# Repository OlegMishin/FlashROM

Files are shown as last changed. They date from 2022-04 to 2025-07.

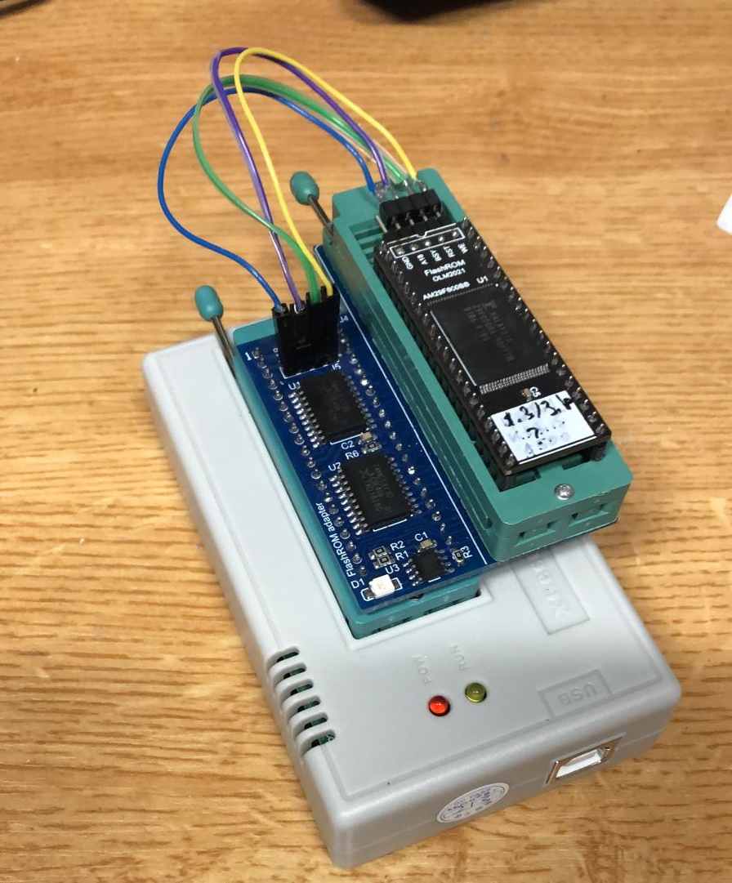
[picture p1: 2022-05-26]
Doc/TL866_flash_writing.jpg

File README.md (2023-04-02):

# FlashROM
Different Flash memory adapters for Commodore/Amiga or other classic computers/devices.

For now there are following types of the FlashROM: 
1. 40pin to be used in Amiga 500.
2. 42 pin designed for my Amiga 1200 but also can be used in A500 rev 8 mainboard.
3. 24 pin for Commodore 64 computers. Replacement for 2316/2332/2364 ROM chips.
4. 28 pin for other devices. Replaces 2764..27512. Supports long and short Flash memory package.

Schematics/BOM and Gerbers located in each ones folder.

# 3D render



# Actual photos

40 pin in A500



42 pin x2 in A1200



24 pin, KERNAL, CHAR, BASIC ROMs replacement in Commodore C64



28 pin



To flash 28 pin FlashROM a simple adapter is needed as the pcb has four test points for flash WE# and extra address lines.
I used a pcb with 32 pin socket and spring needle pins to reach the test points on bottom layer of the pcb.



# FlashAdapter
An adapter for TL866 to program the 16 bit flash memory(40, 42 pin). It based on the circuit:
https://proghq.org/wiki/index.php/TL866_TSOP48_adapter
Circuit diagram, gerbers and ATtiny firmware are in "FlashAdapter" folder.

Four wires required to be connected between the adapter and 40pin FlashROM(as shown below):
A18, #BSY, #RST and #WE. 
For 42pin FlashROM, only needed #BSY, #RST and #WE as A18 and A19 already connected via socket's pins 1 and 2.



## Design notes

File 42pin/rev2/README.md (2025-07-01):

# Using the adapter in different Amiga boards

1. The 42 pin adapter designed mostly for A1200 boards but it can be used in A500 boards as well.
2. Take care about A18 and A19 address inputs of the adapter. In case of 1MiB Flash ROM typically Kickstart ROM can be programmed to two locations: 0x00000 and 0x80000 to let KS start regardless of A18 state.

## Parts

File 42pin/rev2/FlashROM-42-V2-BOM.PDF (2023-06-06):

Bill of Materials | | FlashROM adapter

## (42 pin)

Revision | 2.0
Created by | OLM
Creation date | 06.06.2023 | 21:20:03
Print date | 06.06.2023 | 21:20:09
No. | QuantityDesignator | | Comment | Value | Part | Manufacturer | Description
0 | 1 | C5 | Capacitor | 100nF | 100nF 50VX7R 0603 | | Ceramic capacitor
1 | 1 | J1 | Round pins | 42 pins or x2 single row round male pins | 9081-0-00-15-00-00-08-0‎ | Mill MAx | Round pins
2 | 1 | J2 | Header 6 (2mm) Right angle | PR20C06HBNN | PR20C06HBNN | METZ CONNECT USA Inc. | Header 6 (2mm) Right angle
3 | 4 | R1, R2, R3, R4 | Resistor | 10k | 10k 5% 0603 | | Resistor
4 | 5 | RP2, RP3, RP4, RP5, RP6 | Res. array | 4х10 kOhm | CAT16-103J4 | Bourns | Resistor pack
5 | 1 | U1 | IC | MX29F800CB, 29F800BA | AM29F800BB-70EC | AMD | 8Mb 515K*16 FLASH MEMORY

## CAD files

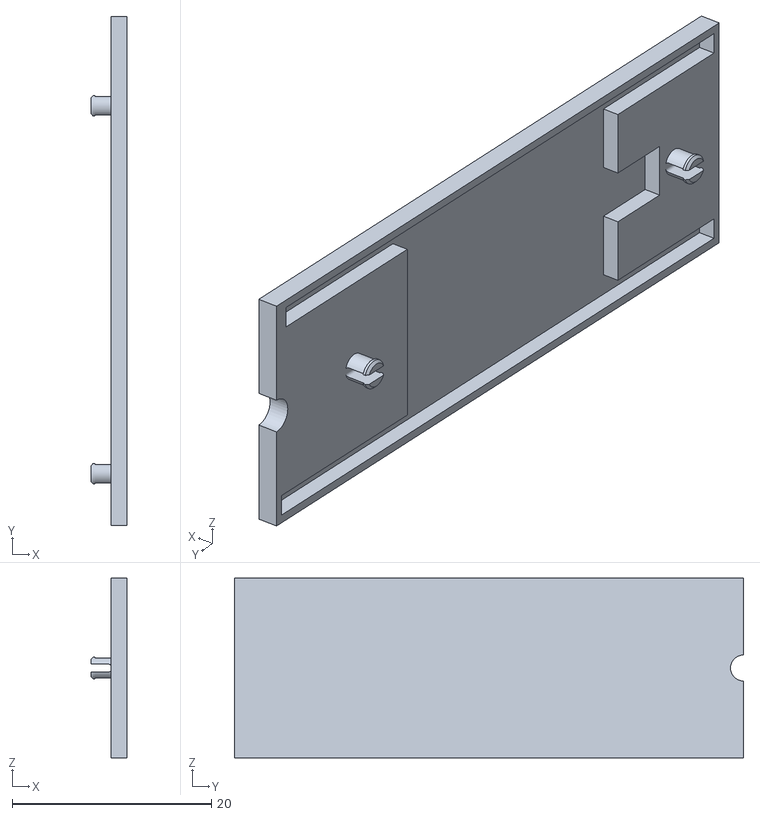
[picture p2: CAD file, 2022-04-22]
40pin/CAD/F40-1-Cover1.STL
3.60 x 51.1 x 18.0

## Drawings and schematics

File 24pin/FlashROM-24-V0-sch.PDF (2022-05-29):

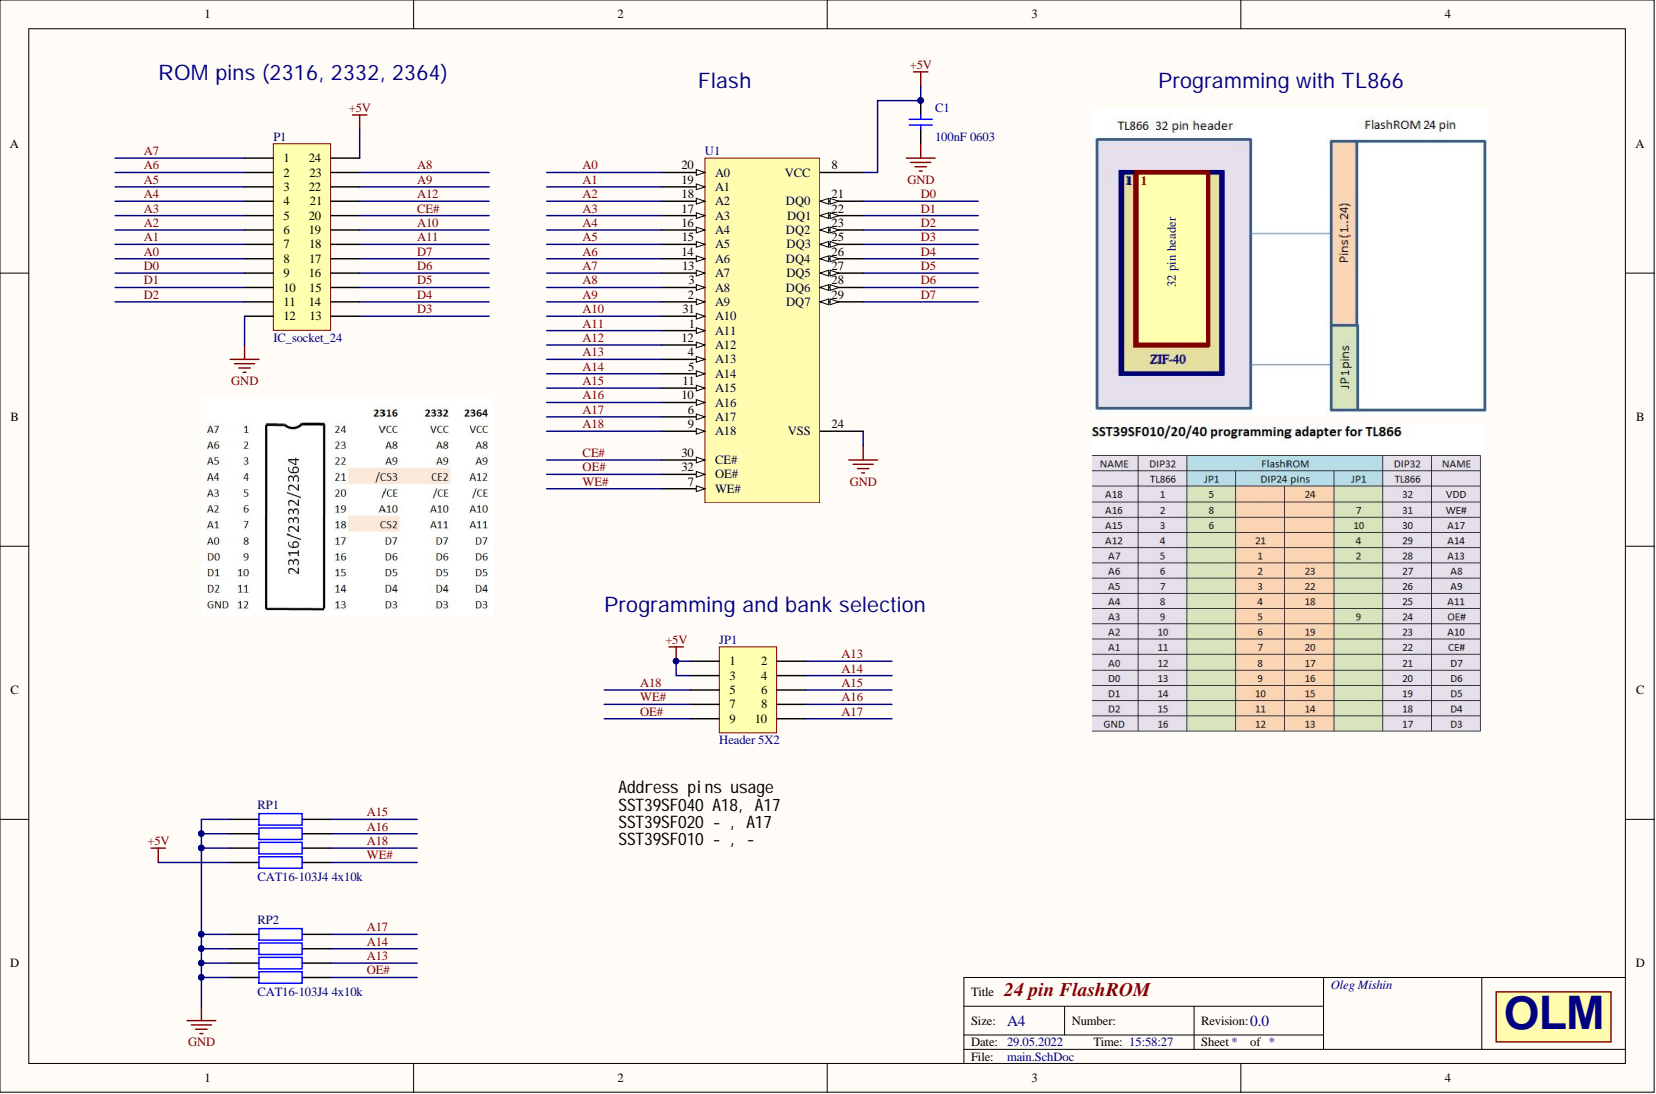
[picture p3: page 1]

Programming and bank selection

24 pin FlashROM Title | Oleg Mishin

Size: | Number: | Revision: 0.0

Date: 29.05.2022 Time: 15:58:27 | | Sheet * of *

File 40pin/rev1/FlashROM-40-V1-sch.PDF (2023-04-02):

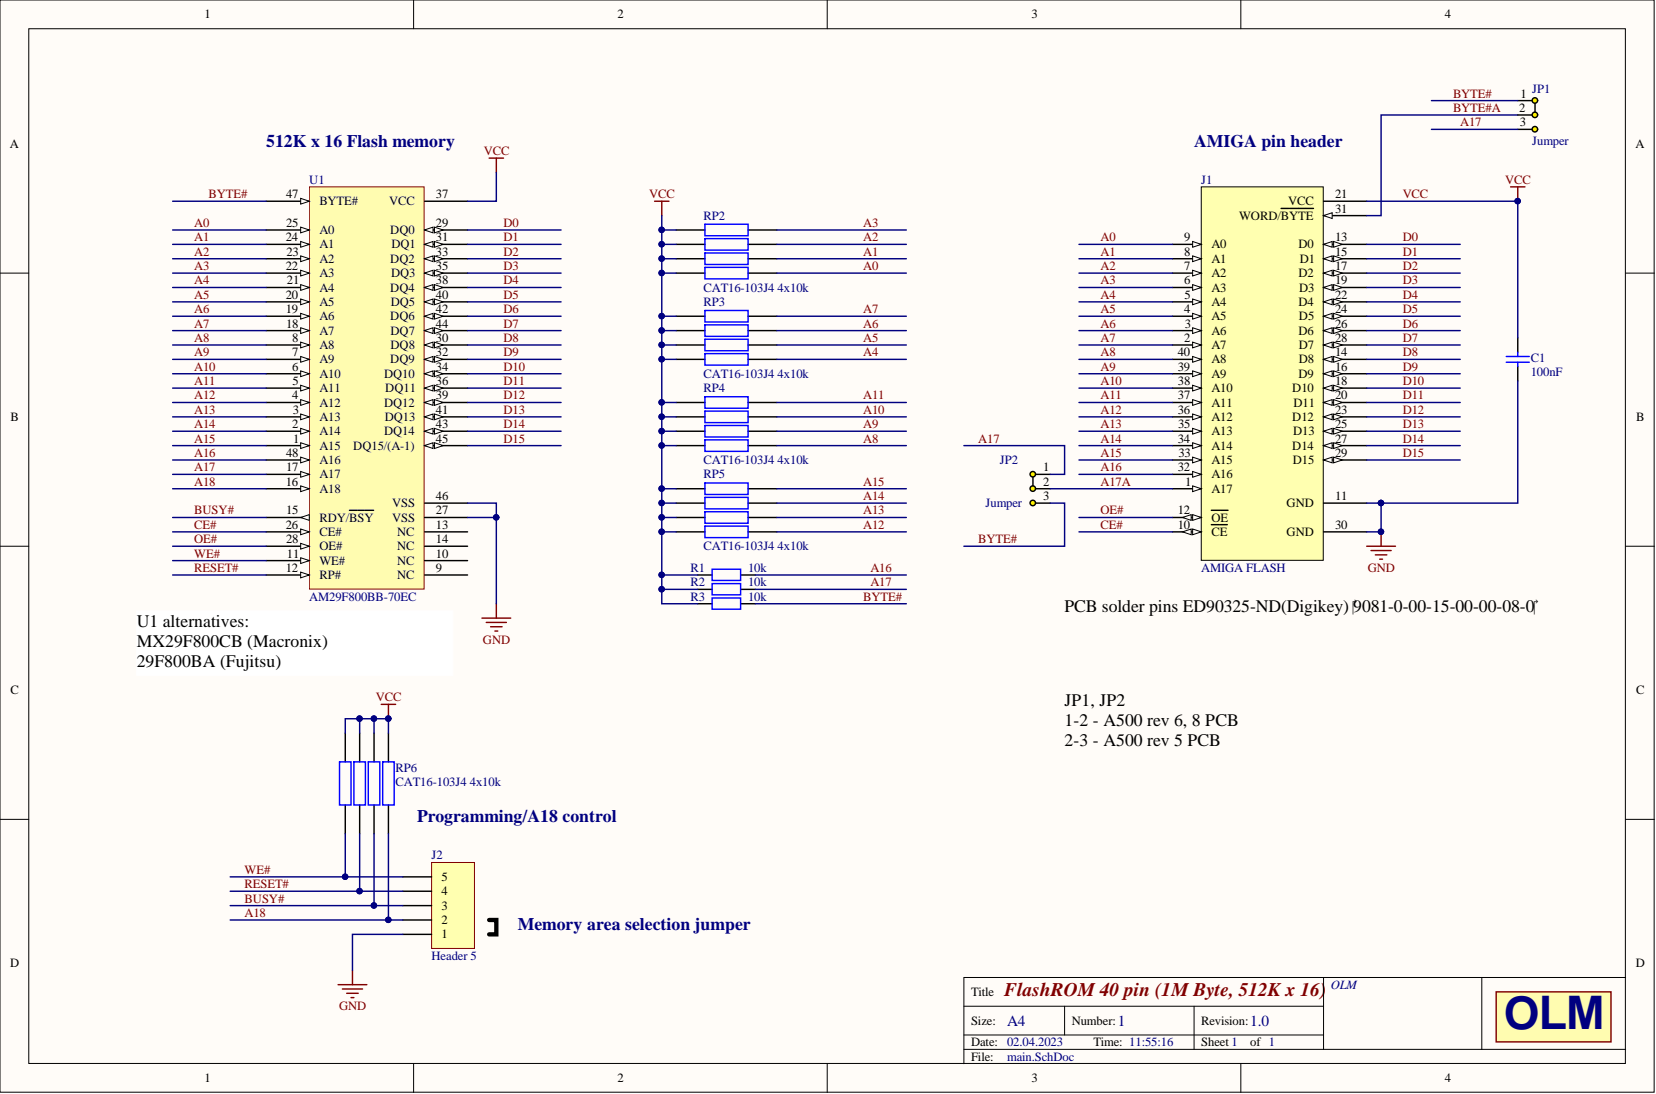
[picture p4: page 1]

R2
R3

PCB solder pins ED90325-ND(Digikey)

Memory area selection jumper

T i tle | OLM

Siz e : A 4 | Numbe r : | Revis ion :

Dat e : T i m e : | | She e t 1 o f 1

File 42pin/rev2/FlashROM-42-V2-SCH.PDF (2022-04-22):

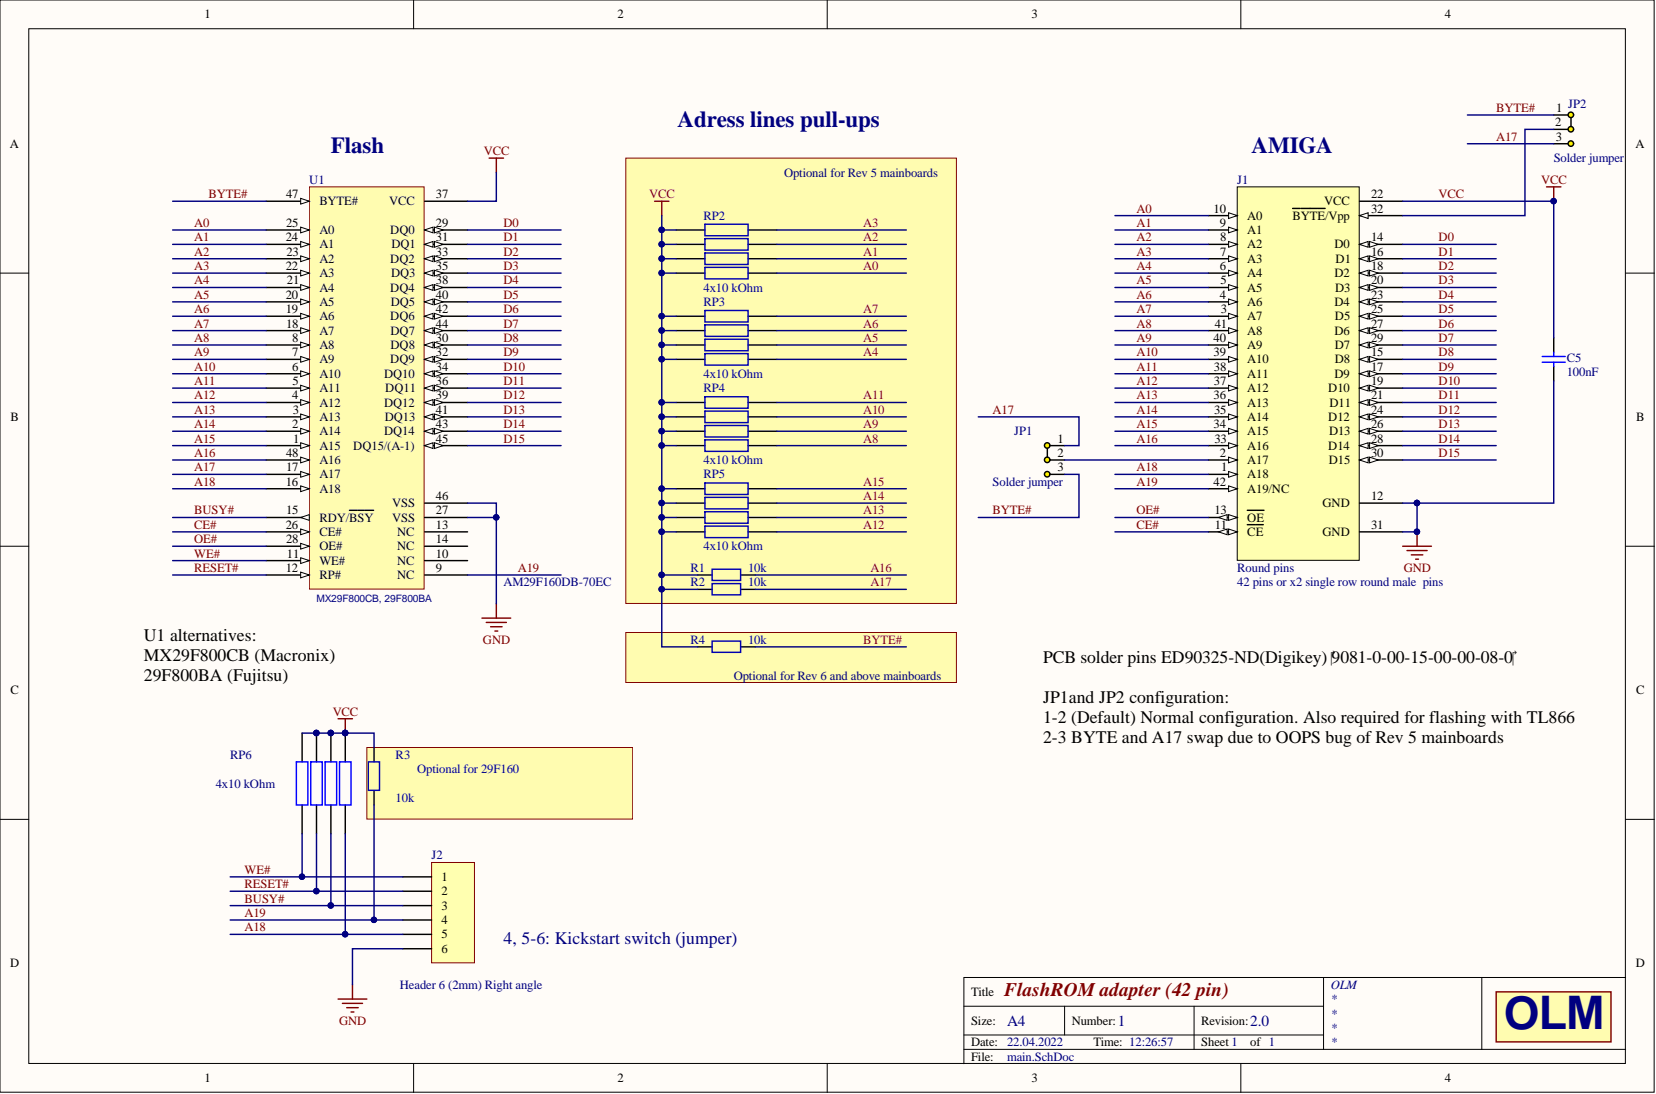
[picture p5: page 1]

Adress lines pull-ups

PCB solder pins ED90325-ND(Digikey)

JP1and JP2 configuration:
1-2 (Default) Normal configuration. Also required for flashing with TL866
2-3 BYTE and A17 swap due to OOPS bug of Re

T i tle | OLM *** *

Siz e : A 4 | Numbe r : | Revis ion :

Dat e : T i m e : | | She e t 1 o f 1

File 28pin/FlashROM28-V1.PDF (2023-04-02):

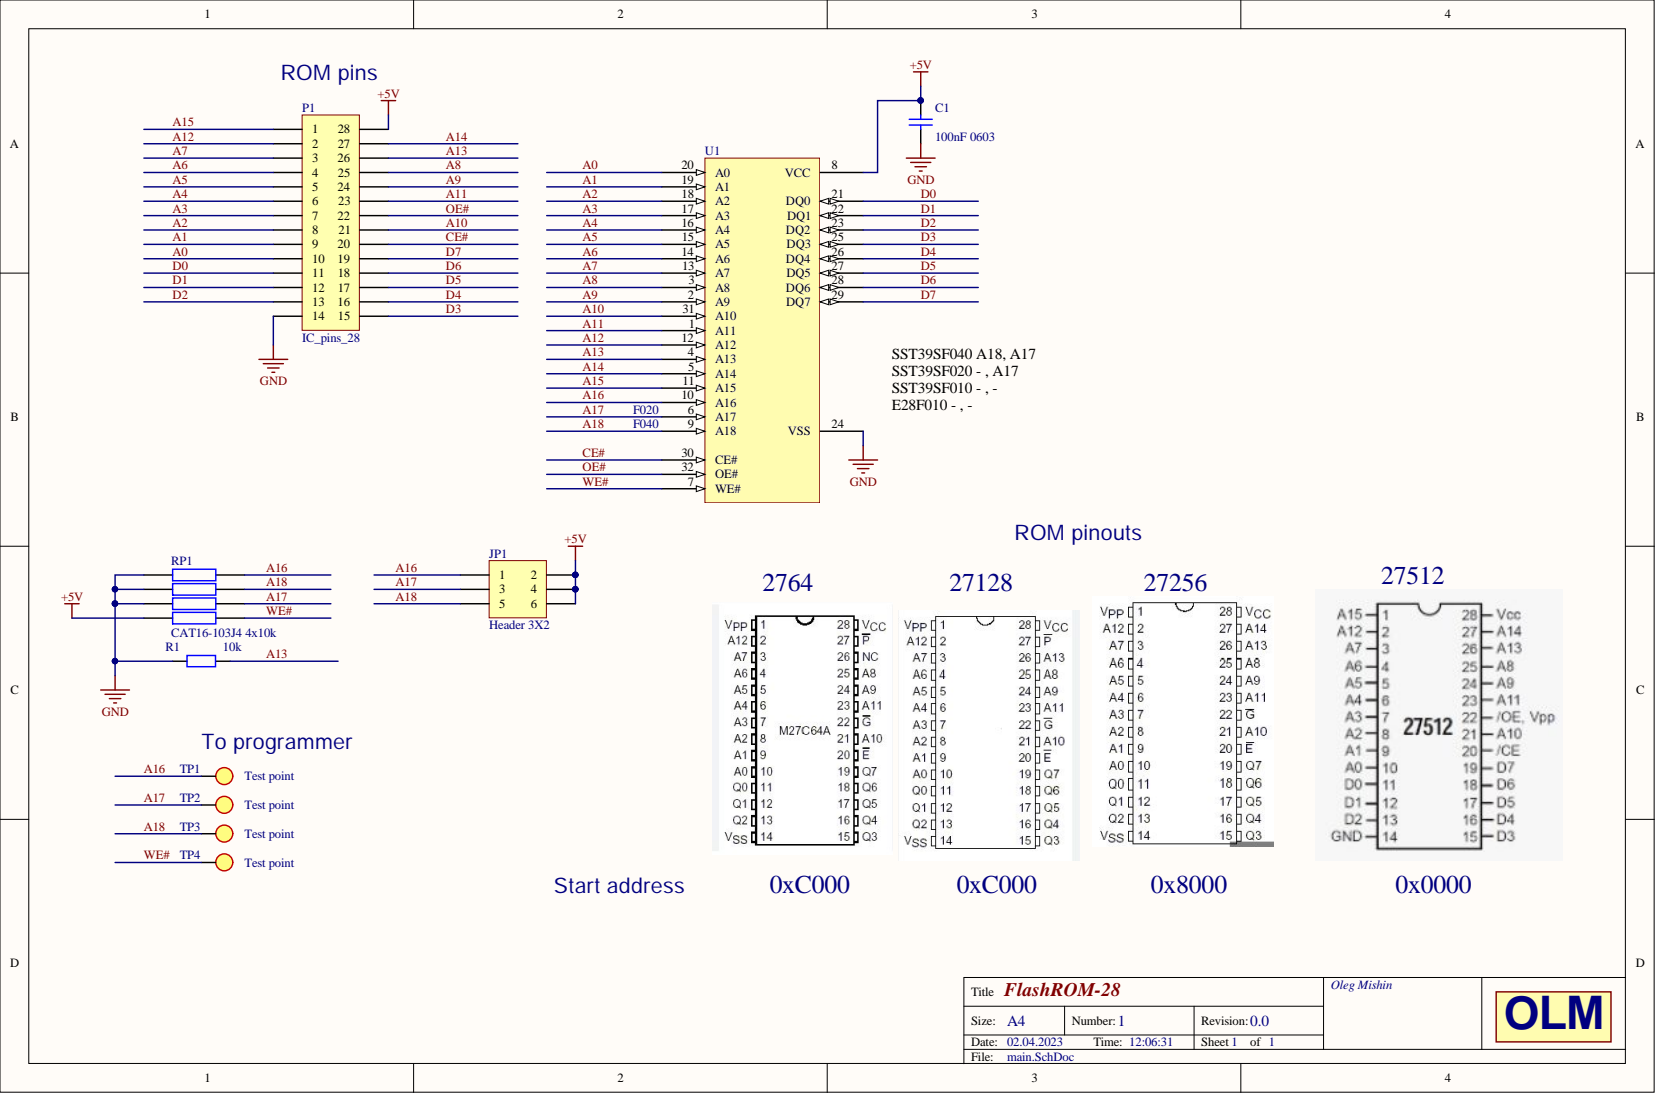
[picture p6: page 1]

FlashROM-28 Title | Oleg Mishin

Size: | Number: 1 | Revision: 0.0

Date: 02.04.2023 Time: 12:06:31 | | Sheet 1 of 1

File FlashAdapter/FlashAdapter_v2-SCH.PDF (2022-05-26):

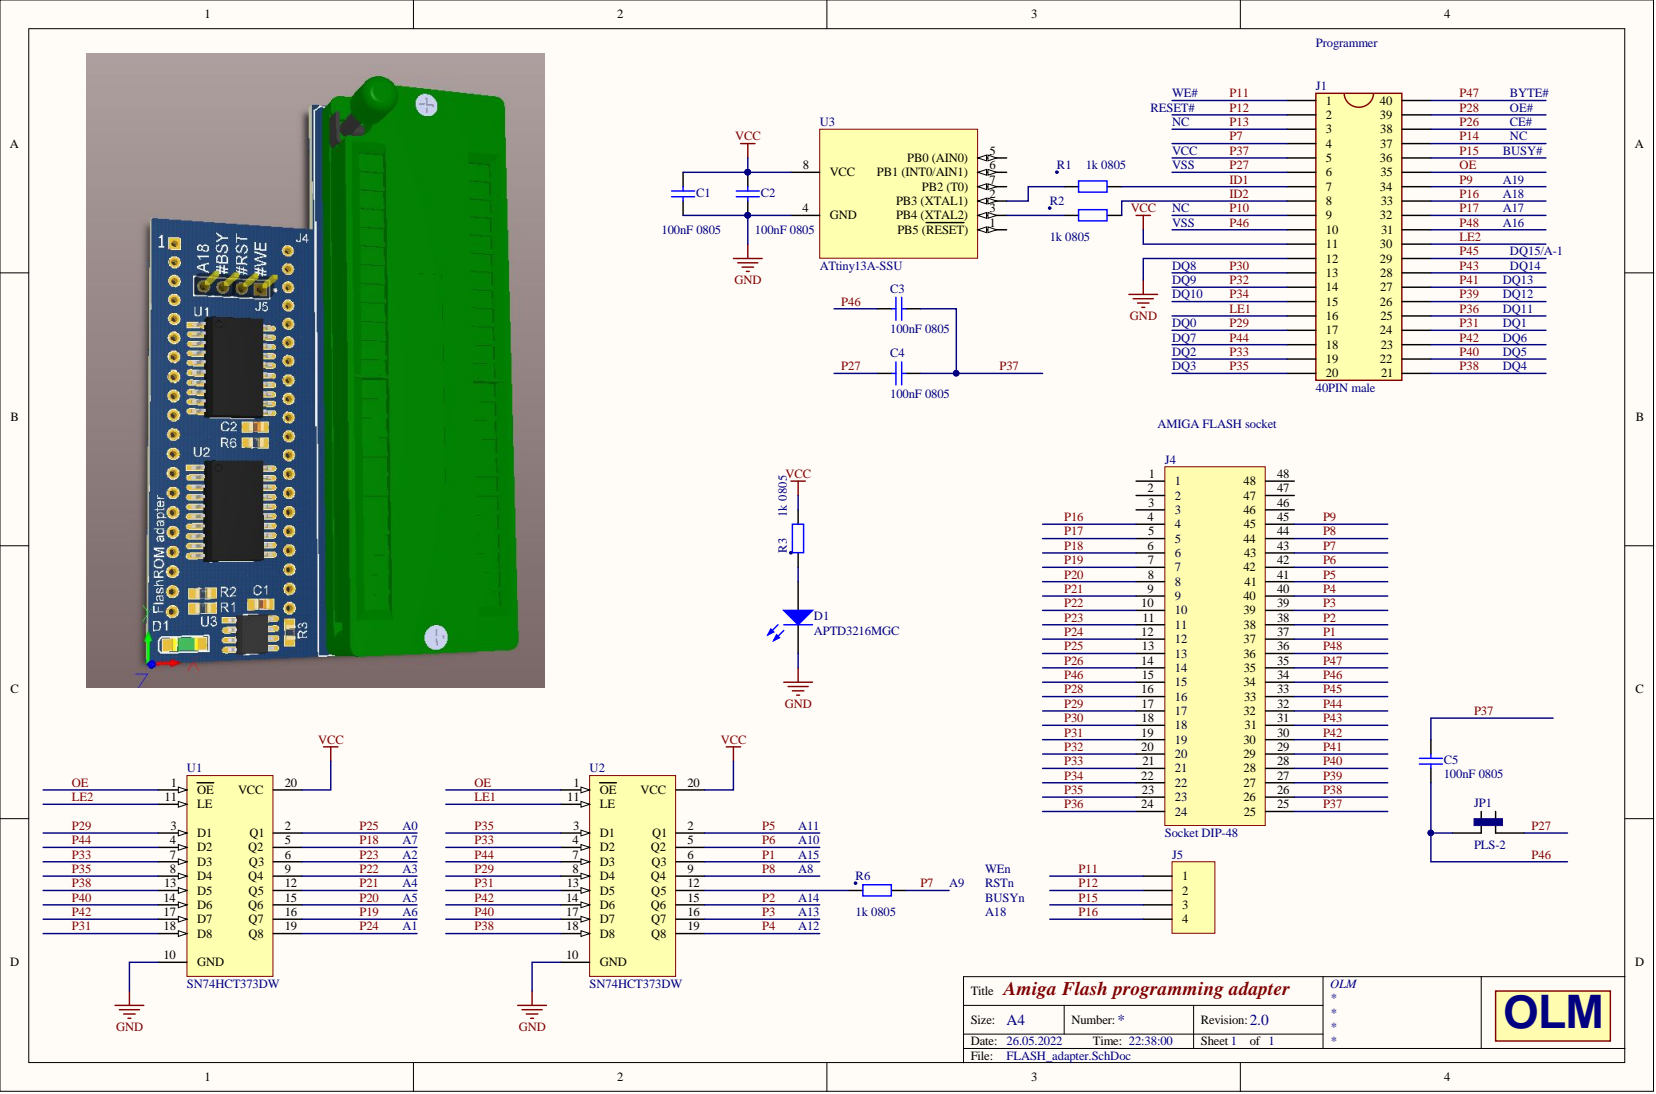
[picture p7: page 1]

T i tle Amiga Flash program ming adapter | OLM *** *

Siz e : A 4 | Numbe r : * | Revis ion : 2.0

Dat e : 26.05.2 022 T i m e : 22: 38: 0 0 | | She e t 1 o f 1

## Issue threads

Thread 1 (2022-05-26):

42pin Possible to program after build? Re-program?

Retrofletch, 2022-05-26:
Ive seen other other flashrom in 40pin form that can be programmed and re-programmed with an adapter, but your 42pin version would need a special adapter im guessing? How do you program these?
I can program the chips before i solder them, but what if i make misstake or i want to change contents? is it possible?
Thank you for releasing great projects!

OlegMishin, 2022-05-26:
Hi,
Only difference between 40 and 42 pin boards is A18 and A19 on pins 1 and 42. As the signals(A18/A19) present also on a small connetor, the same adapter(I use it with TL866 programmer) can be used to reprogram the Flash. I made an adapter board, a clone of TL866's TSOP48 adapter and will publish it later. It is based on this circuit:
https://proghq.org/wiki/index.php/TL866_TSOP48_adapter

Regards
Oleg

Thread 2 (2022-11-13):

Silk screen missing on FlashAdapter

imi2003, 2022-11-13:
Hi

There seems to be the silk screen missing on the bottom side of the gerbers for the FlashAdapter

OlegMishin, 2022-11-13:
Hello,
Thanks for the finding. The gerbers archive has been reuploaded.

Regards
Oleg

Closed 2022-11-13.

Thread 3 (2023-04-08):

Amiga 1200 and AM27C400: why do we need a 42 pin adapter?

piso77, 2023-04-08:
[this is a not issue with the project itself, but more of a hw question]

Hi, i'm using a pair of AM27C400 DIP40 eprom in my Amiga 1200, so why do i need a 42pin flashrom adapter instead?

OlegMishin, 2023-04-08:
Hi,
The 42-pin adapter offers you additional address lines:
- A18 and A19 for AM29F160
- A18 for AM29F800
A18 routed in ReAmiga such way, so you can have two options:
1. To use two Kickstarts switched with jumper "Kickstart switch" on Amiga's pcb
2. Extend Kickstart ROM address space to 1MB and add additional drivers into Kickstart. I use it to add an IDE driver for TF1260.  How to create 1MB ROM described here: https://eab.abime.net/showthread.php?t=45260

Regards
Oleg

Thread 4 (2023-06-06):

BOM discrepancy: PH1RB-06-UA 2mm vs 2.54mm

piso77, 2023-06-06:
Hi Oleg,

the BOM (for the 42pin version) says the 6 pin angled connector PH1RB-06-UA is "2mm" while on digikey[1] the same part is "CONN HEADER R/A 6POS 2.54MM" - looking at the PCB, i think 2mm is the correct answer, but i can't find any other part matching that manufacturer product number then.

1: digikey part number: 2057-PH1RB-06-UA-ND

OlegMishin, 2023-06-06:
Hi Paolo,
Thanks for the finding. Usually I use straight pins and solder them on top of the holes. It is not the best way, but works.
Anyway, I will update the BOM with this part:
PR20C06HBNN (METZ CONNECT USA Inc.), Digikey P/N: 1849-PR20C06HBNN-ND

Regards
Oleg

piso77, 2023-06-07:
Thanks for the answer.

I usually use any connector i have around for through-hole assembly, but somehow none of my connector fits this time around (as in, the hole's diameter seems smaller, while step distance is fine) - both for J2 and PCB solder pins.

OlegMishin, 2023-06-07:
I have the same approach with components :)
Regarding the 6-pin header, looks like its hole is a bit smaller than required. In connector's datasheet recommended hole is 0.8mm but in my footprint it is 0.71. I did not notice as the connectors I have (noname chinese) easily fit the hole.
Anyway, seems it would be better to update hole diameter to 0.8mm.
The PCB solder pins are 0.6mm diameter, so no need to increase hole size, I think.

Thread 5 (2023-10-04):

Which flash do I need to select in the software

tomse, 2023-10-04:
TL866-II plus
I've tried TSOP48 and SOP44
both gives pin errors.

TL866 (using downgraded firmware as mentioned on proghq)
doesn't seem to enable "WE" as writes output but it's never saved in the flash.
I can fill with FF's and it gives no errors - when it's already empty.
trying to program something gives instant verify error, and nothing is saved on the flash.

I've made 2 adapters and 2 flash roms 40 pin, using ST29f800
installed the flash and adapter as shown on the bottom picture.

OlegMishin, 2023-10-05:
Hi,
You need to select in TL866 software exact Flash part number as your Flash IC is. I don't see ST29f800 in device support list. Is it M29F800AB or similar?
I hope you flashed ATtiny micro in the adapter, otherwise it will not work.

tomse, 2023-11-05:
Yes it is  the ST M29F800FB (sorry my bad for not adding the M), pincompatible with M29F800AB.

I was somewhat confused as to which version and programmer to use. You link to a different site where the older software/firmware is said to be used and using the First release of the TL866. Luckily I have both versions.. and using the TL866II Plus with latest software and firmware (right now it's 12.63).

Hooked up like the documentation. ATTiny is flashed. using the 40pin flash.

flashing using the ST29F800AB TSOP48 device (FB doesn't show on the list, but it should be fine as they're pin compatible).

Getting this result.
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

There are no pin1 markers on my ATTiny, but I have the text turned the same way as the 2x74HCT373's
J1 does that need to be closed?
and when should the diode light up? (so far it hasn't)

OlegMishin, 2023-11-05:
Strange, M29F800FB  is in supported devices in the SW I use:
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
"Bad pins" error means there is a problem with soldering or connections. You need to check soldering of the flash chip and connections of pins A17(pin32 of ZIF socket) and BYTE#(pin40) marked in red on the picture.

tomse, 2023-11-05:
I have a version of the original adapter shown above.. this one works, so I've eliminated the programmer as being faulty.
I have 2 adapter boards and 2 flashroms  intermixing these doesn't deviate from the pins that gives errors. I should be very unlucky if I made bad solderings on these boards to give the same error :-P  (I did go through them with a microscope to eliminate bad soldering).

I think you missed my 3 questions beneath the image

OlegMishin, 2023-11-05:
Sorry, missed in deed. ATtiny's orientation is correct. JP1 needs to be closed. The led lits when power supply provided to the flash, when any operation is ongoing(read/write etc).

tomse, 2023-11-05:
I found the issue pin issues... I didn't close the jumpers on the flash chips - now I've shorted J1 and J2 for Rev6
(perhaps this needs to be added to the documentation / Q&A?)

now I'm down to data isn't being written to the chip.
tried both adapters and both flash chips - something else I might have missed?
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

OlegMishin, 2023-11-06:
If you enable "Check ID" does it work? Which ID actually read from the flash?
Even if M29F800FB is pin compatible with M29F800AB it doesn't mean that programming algorithm is the same.
You can try to select M29F800FB from Numonix.

OlegMishin, 2023-11-07:
To ckeck if the ATtiny is the bad guy, you can remove R1 and R2 and check. I guess the SW should report an adapter error.
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

Just to confirm, A18, BSY, RST and WE wires between adapter and FlashROM are on their place, right?

tomse, 2023-11-08:
yes... the 4 cables are connected to their respective connectors.
I'll try and remove the resistors.. just to see what happens..

OlegMishin, 2023-11-15:
Sorry, no more ideas.... I have never had any issue with my adapter using many different Flash ICs.
Looks like a soldering problem or pcb defekt. Have you built only one?

tomse, 2023-11-15:
I built 2 adapters, and 2 flash roms (40pins)

thanks for the help though :-)

I'll leave the issue open, that I can make a closing comment if I find the error.. otherwise I'll close it on a later time as unreproducable..
is that ok with you?

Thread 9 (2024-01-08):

Alliance M29F800FB5AN6E2 weird behavior

mlorenzati, 2024-01-08:
I Built your adapter  with M29F800FB5AN6E2 (alliance) and I was struggling to do in a trusty way:
- checking id
- erasing
- verifying blank
- program
- verify after what programmed

On one of the test I heat the pcb with the hot air soldering station and while "more than warm" I was able to perform all operation and also use it on the A600.
Once cool down failed again...

Is it the flash? flux? something else you can imagine?

mlorenzati, 2024-01-08:
I answer myself an close the issue, the memory is extremely sensible to the flux, I iterated alcohol with a thin hair toothbrush (the other I had could not get well between pins) and hot air.
Now I have a dual KS for my A600! Thanks!
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

Closed 2024-01-08.

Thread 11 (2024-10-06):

Programming 24 pin tsop32

PicoElements, 2024-10-06:
Hello,
i need to program some SST29sf040 on 24 pin pcb for my C64 Kernel .
Can i program with your flash adpater? i see only WE A18 and 5v on. On the flash adapter i have WE, RST, Busy,A18.
Trying with WE and A18 only the chip is not recognized..
Can you help me?

Thanks for reading,
Stefano

OlegMishin, 2024-10-08:
Hi Stefano,
I don't have any adapter for 24pin FlashROM so far. For flashing I did use a prototype board with 32 pin male header for TL866 connection and 24 pin socket + 10 pin header for higher address lines and OE#/WE# signals.

Br
Oleg

PicoElements, 2024-10-08:
Thank you Oleg. I'm preparing an adapter right now. Just to know, i followed your schematics, th eonly doubt is which signals are required to program an SST39sf040 i.e.  I would exclude 5v headers on the 24 pin pcb.. The 5v and gnd are taken from the TL866 pins . Am i doing right?

OlegMishin, 2024-10-08:
No problem. You are right. You need to follow pinout of  SST39SF040 to make all connections available between the Flash IC and TL866's socket.
Actually, the connections already in the schematics:
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

OlegMishin, 2024-10-28:
Hi,
It depends on your target application as the FlashROM adapter is just wires betwiin DIP pins and its Flash memory.
I've never seen 3.3V DIP24 ROM.
Luckily SF are still available at Digikey/Mouser/etc.

PicoElements, 2024-11-07:
Hi,
trying to program Intel E28F010 the TL866 programmer gives FF FF as ID. SST39SF040s instead work like a charm. Any advice when programming intel above?
Thanks,
Stefano

OlegMishin, 2024-11-08:
Hi Stefano,
In my memory, E28F010 has longer package and it doesn't fit to the 24-pin FlashROM board. Or did you find short one(as SST39SF0xx)?
I used the Intel Flash E28F010 in my other adapter board without any issues. Maybe the Flash is dead or soldering problem.
I would suggest to check the Flash at first with original TSOP adapter as below to be sure it is working.
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

Br
Oleg

PicoElements, 2024-12-16:
Hi Oleg. Actually the adapter in your photo is needed, exaclty that one. Now it works thanks! Look , for C64 Basic i.e. did you copy the 8k bin over and over to fit the 010 capacity?
Thanks,
Stefano

OlegMishin, 2024-12-17:
Hello Stefano,
Usually I check address lines in which state they are and write ROM image to the exact address.
As the adapter has high address lines at jumper block, it is possible to write multiple ROMs to different adresses.
~Oleg

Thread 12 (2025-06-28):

Add programming info for 42 pin ROMs

Feliksas, 2025-06-28:
Please update the readme with the note on programming 42pin 1 MiB ROM chips with info on the necessity to load the standard 512KB split ROM images in Xgpro twice - first at standard flash chip offset 00000, and second time at chip offset 80000 without erasing previous buffer contents.
It may be not immediately obvious, since ROM address lines 18 and 19 are actually connected on the Amiga, but the ROM needs to output correct data no matter what states those lines are set to. ROM splitters copy the ROM contents twice by default, so loading them is only required twice, effectively producing 4 identical segments of 256 KiB.

I sure fell into this trap, so would be nice to have that info in README :)

OlegMishin, 2025-07-01:
Hi @Feliksas,
Thanks for your feedback. I wrote a couple of words regarding A18 and A19 in readme for 42 pin adapter to give a general direction for one building the adapter.
In general, as the adapter can be used in different Amiga revisions, I'd like to leave the address selection to the user. E.g. in my configuration, I use it in ReAmiga1200 with 1MB Kickstart image, therefore A18 is controlled by CPU.

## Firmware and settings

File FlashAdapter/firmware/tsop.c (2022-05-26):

/*
* tsop.c
*
* Created: 22.02.2014 07:22:55
*  Author: radioman
*/

#define F_CPU 4800000UL //Internal 4.8Mhz clock

#include <avr/io.h>
#include <avr/interrupt.h>
#include <util/delay.h>
#include <avr/pgmspace.h>

//Extracted xor table from TL866 firmware at 0x0196AA
const unsigned char xortable[] PROGMEM =
{
	0x48, 0x0D, 0x11, 0xB6, 0xA4, 0x76, 0xA0, 0xF6, 0x66, 0xE9, 0x55, 0xE5, 0xAC, 0x20, 0xDB, 0x16,
	0x0C, 0x65, 0x1F, 0x53, 0x7A, 0xEC, 0x55, 0x8F, 0x6C, 0x65, 0x3D, 0x1C, 0x3C, 0xD2, 0xA4, 0x1F,
	0xCD, 0x96, 0x2D, 0x40, 0x71, 0xCF, 0x51, 0xA6, 0x0A, 0xE6, 0xA5, 0x22, 0x70, 0x65, 0x5B, 0xAA,
	0x13, 0x08, 0x0C, 0x0A, 0xE2, 0x16, 0xB5, 0xD6, 0x6B, 0xF1, 0xFF, 0xA3, 0x43, 0xEC, 0xC3, 0x76,
	0xA8, 0x5E, 0xCD, 0x7D, 0x65, 0xF5, 0xE0, 0xFD, 0xF6, 0x4C, 0xFB, 0x8C, 0xED, 0xBF, 0xDB, 0x80,
	0x94, 0x7E, 0xC1, 0xA7, 0xD4, 0xE0, 0x75, 0x39, 0x55, 0xFA, 0x8B, 0x0A, 0xE7, 0x71, 0xE5, 0x04,
	0x21, 0x8C, 0x79, 0xD5, 0x47, 0x8D, 0x54, 0xE5, 0x71, 0x42, 0xDF, 0x8B, 0xEA, 0xD7, 0x62, 0x80,
	0xD7, 0xEE, 0xC6, 0x94, 0x19, 0xF1, 0x9F, 0x9F, 0x74, 0xA7, 0x6A, 0xBB, 0xF0, 0x06, 0x12, 0xB0,
	0x7F, 0x49, 0xBA, 0xB0, 0xE1, 0x42, 0xB6, 0x45, 0xC5, 0xF0, 0xDA, 0x87, 0x31, 0x54, 0xF8, 0x92,
	0x23, 0x81, 0xA4, 0x37, 0x79, 0xF3, 0x3A, 0xF2, 0x0E, 0x21, 0x23, 0x1C, 0x26, 0x55, 0x53, 0x62,
	0x0C, 0xBC, 0x16, 0x76, 0xF9, 0xB9, 0x0D, 0x04, 0x38, 0x7F, 0x73, 0xE8, 0x88, 0xDF, 0xA5, 0x9E,
	0xC2, 0x5E, 0xE2, 0xFA, 0xBB, 0x8B, 0x4F, 0x19, 0x6C, 0x90, 0x3E, 0x97, 0x50, 0x06, 0xAF, 0x02,
	0x0E, 0x0E, 0x17, 0x8F, 0x58, 0x9D, 0x61, 0x0C, 0x13, 0x17, 0x33, 0x16, 0xB8, 0x20, 0x72, 0x8C,
	0xFA, 0xAF, 0x08, 0x44, 0xA9, 0x63, 0xE5, 0xFC, 0xD6, 0x1B, 0x43, 0x93, 0x38, 0xC1, 0x2F, 0x79,
	0xCE, 0x66, 0x45, 0x64, 0xC6, 0x94, 0xBB, 0x44, 0x9E, 0xDF, 0xA1, 0x7A, 0x89, 0xBE, 0x66, 0x44,
	0x14, 0x99, 0x9F, 0x7C, 0x09, 0x23, 0x04, 0x83, 0x93, 0xEA, 0xBB, 0x78, 0xA4, 0x2D, 0xDA, 0xAD
};

/*Constant response packet. This packet structure is simple:
1.Xor bytes from offset 4 to 35(0x74 to 0xBA) with byte at offset 0 (0x57)
2.Compute a checksum of first 36 bytes; the result must match the last byte (0x7D). If this checksum doesn't match then the TL866 report "V0 is illegal"

Actually the TL866 firmware will check if the first 8 bytes are: 51 33 51 00 c8 9d d4 3e ; if yes then return FAKE!
Now what happen if we put 37 bytes of '0'? well xor zero by zero equal zero and checksum of an infinite number of zeros is zero! and this will pass the genuine check. Very weak algorithm.
But we keep this as original chip does. Thanks Gerard for your captures.
*/
const unsigned char response[] PROGMEM =
{
	0x57, 0x33, 0x57, 0x00, 0x74, 0x87, 0x75, 0xC5, 0xE9, 0xE6, 0xF5, 0xEE, 0x95, 0x12, 0x5B, 0x66,
	0x1F, 0x0A, 0x68, 0xFC, 0x8A, 0x80, 0x3B, 0xFD, 0x72, 0x01, 0x7E, 0x38, 0x2B, 0x4D, 0xC3, 0x43,
	0xC7, 0xA5, 0x9A, 0xBA, 0x7D
};


//Data line port defines
#define DATA_LINE_DDR		DDRB
#define DATA_LINE_OUT_PORT	PORTB
#define DATA_LINE_IN_PORT	PINB
#define DATA_LINE_PIN		4


//clock line port defines
#define CLOCK_LINE_DDR		DDRB
#define CLOCK_LINE_PORT		PINB
#define CLOCK_LINE_PIN		3

//helper macros
#define data_line		(DATA_LINE_IN_PORT &(1<<DATA_LINE_PIN))
#define clock_line		(CLOCK_LINE_PORT &(1<<CLOCK_LINE_PIN))
#define data_line_high		(DATA_LINE_OUT_PORT |= (1<<DATA_LINE_PIN))
#define data_line_low		(DATA_LINE_OUT_PORT &= ~(1<<DATA_LINE_PIN))
#define set_data_line_out	(DATA_LINE_DDR |=(1<<DATA_LINE_PIN))
#define set_data_line_in	(DATA_LINE_DDR &= ~(1<<DATA_LINE_PIN))

//machine state
#define STATE_RECEIVE		0
#define STATE_TRANSMIT		1


unsigned char buffer[47];//Receive/Send buffer
volatile unsigned char state_machine;//keep the machine state
unsigned char bit;
unsigned char byte;

static inline unsigned int crc16_ccitt(unsigned char* data, unsigned int len);
static inline void spi_receive();
static inline void spi_send();
static inline void check();

//Main routine
int main(void)
{
	DATA_LINE_OUT_PORT |=(1<<DATA_LINE_PIN);//pull-up on data line
	CLOCK_LINE_PORT |=(1<<CLOCK_LINE_PIN);//pull-up on clock line
	PCMSK |=(1<<CLOCK_LINE_PIN);//set PCMSK clock line external interrupt mask
	GIMSK|=(1<<PCIE);//activate external sense interrupts
	bit=0;
	byte=0;
	state_machine=STATE_RECEIVE;//we start in receive mode
	_delay_ms(5);//wait for lines to settle. 
	sei();//enable interrupts
	while(1)//just nothing here. From now all tasks are interrupt driven.
	{
	}
}


//CRC16_CCITT routine
unsigned int crc16_ccitt(unsigned char* data, unsigned int len)
{
	unsigned int crc=0;
	while(len--)
	{
		crc  = (unsigned char)(crc >> 8) | (crc << 8);
		crc ^= *data++;
		crc ^= (unsigned char)(crc & 0xFF) >> 4;
		crc ^= (crc << 8) << 4;
		crc ^= ((crc & 0xFF) << 4) << 1;
	}
	return crc;
}


//Simple interrupt routine handler
ISR(PCINT0_vect)
{
	if(clock_line)//If clock line was changed from 0 to 1 then we call receive/send routines
	{
		if(!state_machine)
		spi_receive();
		else
		spi_send();
	}
	
}

//Receive 10 bytes routine. Driven by clock line
static inline void spi_receive()
{
	buffer[byte]<<=1;
	if(data_line)
	buffer[byte]|=1;
	bit++;
	bit &=7;
	if(!bit)
	{
		byte++;
		if(byte==10)
		{
			byte=0;
			set_data_line_out;//switch the data line in output mode
			check();//check and prepare transmit buffer
			if (buffer[byte] & 0x80)//put the first bit to data line
			data_line_high;
			else
			data_line_low;
			buffer[byte]<<=1;
			bit++;
			state_machine=STATE_TRANSMIT;
		}
	}
}

//Send 47 bytes routine. Driven by clock line.
static inline void spi_send()
{
	if (buffer[byte] & 0x80)
	data_line_high;
	else
	data_line_low;
	buffer[byte]<<=1;
	bit++;
	bit &=7;
	if(!bit)
	{
		byte++;
		if(byte==47)
		{
			byte=0;
		}
	}
}

//check the received data
static inline void check()
{
	unsigned char i,index;
	//swap byte 2 by 8 and 4 by 9
	i=buffer[8];
	buffer[8]=buffer[2];
	buffer[2]=i;
	i=buffer[9];
	buffer[9]=buffer[4];
	buffer[4]=i;
	//calculate crc16_ccitt of the first 10 bytes. If they match then we change the state machine in transmit mode.
	if(crc16_ccitt(buffer,8)==((buffer[9] << 8) | buffer[8]))
	{
		index=(buffer[0] & buffer[7]);//The starting index for byte xoring is byte 0 AND 7
		for(i=0;i<10;i++)
		{
			buffer[i] ^=pgm_read_byte(&xortable[index++]);//xor first 10 bytes against a xortable
			index &=0xFF;//index is incremented modulo 256
		}
		for(i=0;i<37;i++)
		{
			buffer[i+10]=pgm_read_byte(&response[i]);//copy the next predefined 37 bytes from flash to the SRAM buffer
		}
	}
}

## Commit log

2022-04-22 Initial upload
    [F40-1-Cover1.STL]
2022-11-13 Update FlashAdapter_V2.zip
    Fixed missing silkscreen on bottom side
2023-04-02 Uploaded 28 pin version
2023-06-06 Update FlashROM-42-V2-BOM.PDF
    BOM update with 6 pin header part number
2023-06-07 Increased hole size of 6 pin header
